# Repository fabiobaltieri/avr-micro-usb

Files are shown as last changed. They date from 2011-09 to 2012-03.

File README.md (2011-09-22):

AVR MICRO USB
==========

This project is a small USB key based on Atmel ATtiny45-like microcontrollers.

License
-------

This program is free software: you can redistribute it and/or modify
it under the terms of the GNU General Public License as published by
the Free Software Foundation, either version 2 of the License, or
(at your option) any later version.

Contents
--------

    COPYING     text version of the GPL
    README      this file
    firmware/   source directory for firmware files
    hardware/   source directory for the hardware design files

Firmware
--------

Building requires an avr-gcc toolchain, in the firmware/ directory, to build
run:

    make main.hex

Flashing the firmware on the device requires avrdude and a compatible hardware
programmer. Default configuration is stored at the beginning of the Makefile.
To program with the default configuration, run:

    make flash

Fuses can be configured running:

    make fuses

Hardware
--------

All hardware files (schematic, layout and libraries) are in CadSoft Eagle
format.

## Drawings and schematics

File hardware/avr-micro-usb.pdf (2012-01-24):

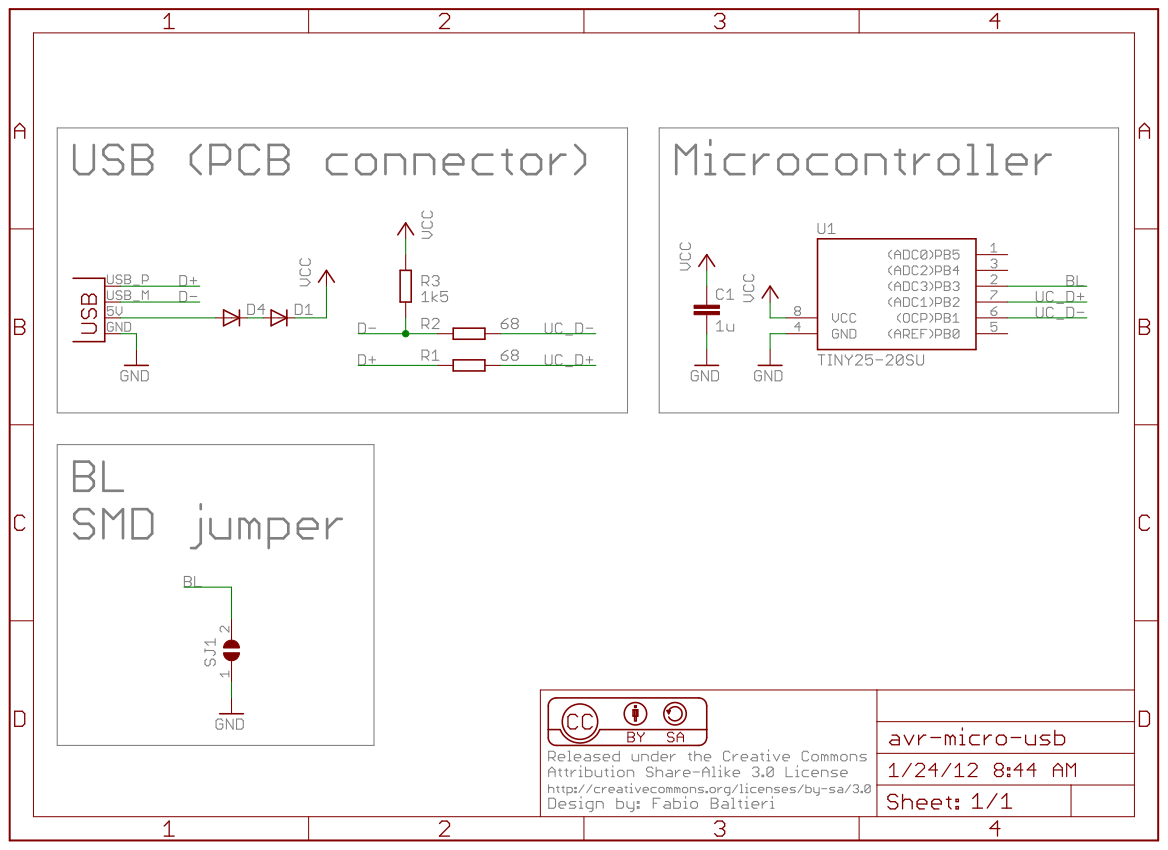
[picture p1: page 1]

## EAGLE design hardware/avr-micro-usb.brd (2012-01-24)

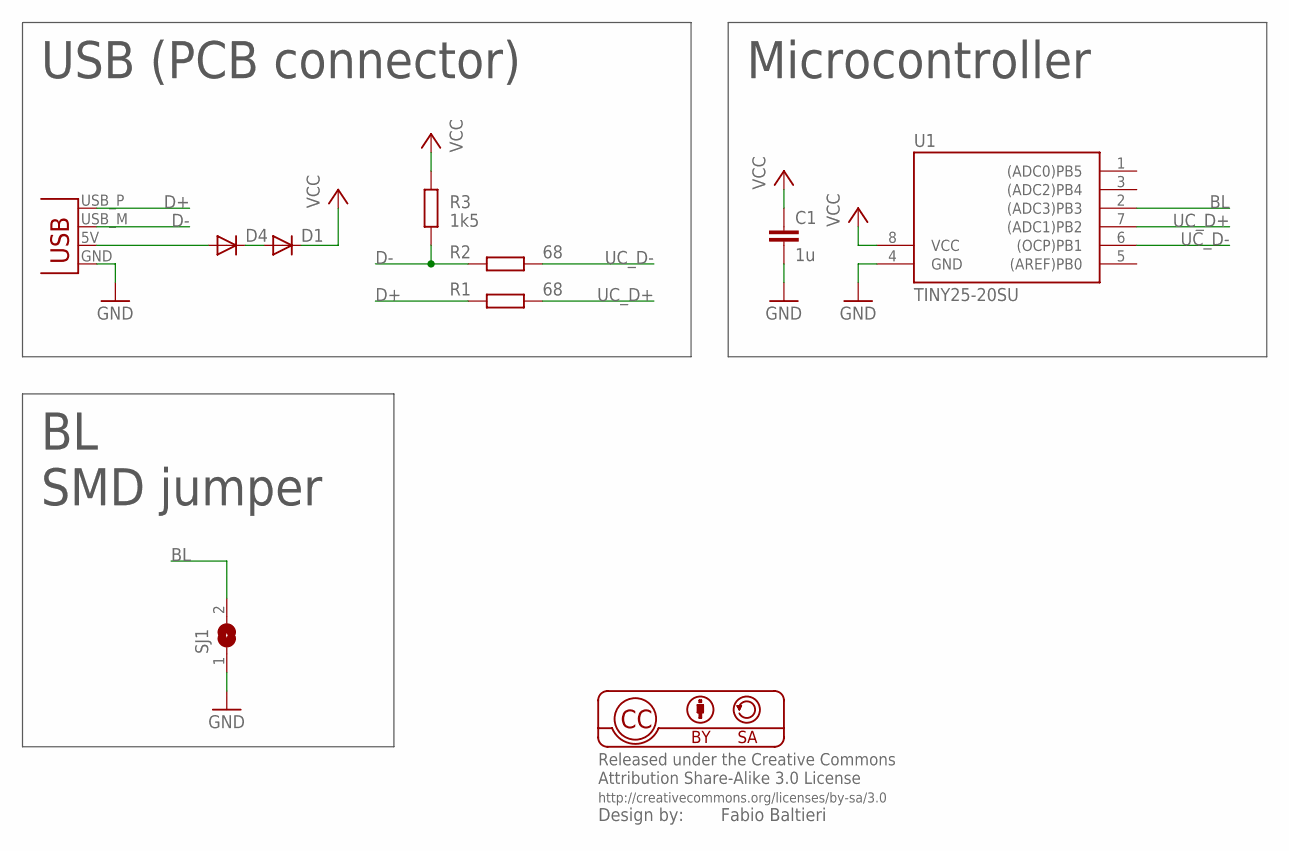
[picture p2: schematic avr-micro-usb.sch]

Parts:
C1: 1u; C0805
D1, D4: DIODE-MINIMELF; MINIMELF
R1, R2: 68; R0603
R3: 1k5; R0603
SJ1: SJ
U1: TINY25-20SU; SOIC8
X1: USBPCB; USB-A-PCB

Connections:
BL: SJ1.2, U1.2 ((ADC3)PB3)
D+: R1.2, X1.USB_P (D+)
D-: R2.2, R3.1, X1.USB_M (D-)
GND: C1.2, SJ1.1, U1.4 (GND), X1.GND
unnamed: D4.A, X1.5V (VBUS)
unnamed: D1.A, D4.C
UC_D+: R1.1, U1.7 ((ADC1)PB2)
UC_D-: R2.1, U1.6 ((OCP)PB1)
VCC: C1.1, D1.C, R3.2, U1.8 (VCC)

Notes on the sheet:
USB (PCB connector)
SMD jumper
Microcontroller

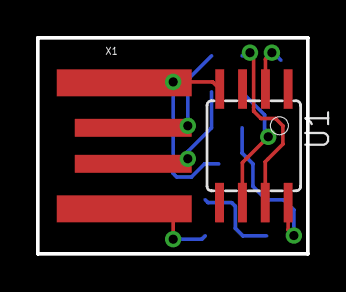
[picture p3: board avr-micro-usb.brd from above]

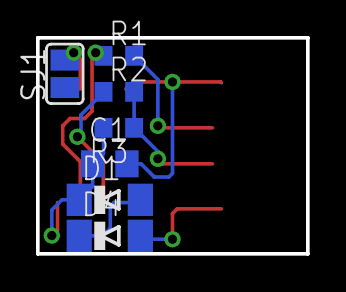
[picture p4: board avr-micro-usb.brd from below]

Board: 2 copper layers, 15.0 x 12.0 mm, 9 parts (7 on the bottom side), 9 nets.

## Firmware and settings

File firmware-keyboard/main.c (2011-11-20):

/*
 * Copyright 2011 Fabio Baltieri (fabio.baltieri@gmail.com)
 *
 * Based on the original V-USB code written by
 *  Christian Starkjohann, Copyright 2006, OBJECTIVE DEVELOPMENT Software GmbH
 *
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
 */

#include <avr/io.h>
#include <avr/interrupt.h>
#include <avr/pgmspace.h>
#include <avr/eeprom.h>
#include <avr/wdt.h>
#include <string.h>

#include "usbdrv.h"
#include "oddebug.h"

/* ----------------------- hardware I/O abstraction ------------------------ */

static void hardwareInit(void)
{
  uchar	i, j;

  PORTB = 0x08;   /* activate all pull-ups */
  DDRB = 0;       /* all pins input */
  j = 0;
  while(--j){     /* USB Reset by device only required on Watchdog Reset */
    i = 0;
    while(--i); /* delay >10ms for USB reset */
  }
  DDRB = 0x08;    /* 0000 0010 bin: remove USB reset condition */
  /* configure timer 0 for a rate of 12M/(1024 * 256) = 45.78 Hz (~22ms) */
  TCCR0A = 5;      /* timer 0 prescaler: 1024 */
}

/* ------------------------------------------------------------------------- */
/* ----------------------------- USB interface ----------------------------- */
/* ------------------------------------------------------------------------- */

static uchar    reportBuffer[8];    /* buffer for HID reports */
static uint8_t  reportIndex;
static uchar    idleRate;           /* in 4 ms units */

PROGMEM char usbHidReportDescriptor[USB_CFG_HID_REPORT_DESCRIPTOR_LENGTH] = { /* USB report descriptor */
  0x05, 0x01,                    // USAGE_PAGE (Generic Desktop)
  0x09, 0x06,                    // USAGE (Keyboard)
  0xa1, 0x01,                    // COLLECTION (Application)

  0x05, 0x07,                    //   USAGE_PAGE (Keyboard)
  0x19, 0xe0,                    //   USAGE_MINIMUM (Keyboard LeftControl)
  0x29, 0xe7,                    //   USAGE_MAXIMUM (Keyboard Right GUI)
  0x15, 0x00,                    //   LOGICAL_MINIMUM (0)
  0x25, 0x01,                    //   LOGICAL_MAXIMUM (1)
  0x75, 0x01,                    //   REPORT_SIZE (1)
  0x95, 0x08,                    //   REPORT_COUNT (8)
  0x81, 0x02,                    //   INPUT (Data,Var,Abs)

  0x95, 0x01,                    //   REPORT_COUNT (1)
  0x75, 0x08,                    //   REPORT_SIZE (8)
  0x81, 0x03,                    //   INPUT (Cnst,Var,Abs)

  0x95, 0x06,                    //   REPORT_COUNT (6)
  0x75, 0x08,                    //   REPORT_SIZE (8)
  0x25, 0xff,                    //   LOGICAL_MAXIMUM (101)
  0x19, 0x00,                    //   USAGE_MINIMUM (Reserved (no event indicated))
  0x29, 0xff,                    //   USAGE_MAXIMUM (Keyboard Application)
  0x81, 0x00,                    //   INPUT (Data,Ary,Abs)

  0xc0                           // END_COLLECTION
};
/* We use a simplifed keyboard report descriptor which does not support the
 * boot protocol. We don't allow setting status LEDs and we only allow one
 * simultaneous key press (except modifiers). We can therefore use short
 * 2 byte input reports.
 * The report descriptor has been created with usb.org's "HID Descriptor Tool"
 * which can be downloaded from http://www.usb.org/developers/hidpage/.
 * Redundant entries (such as LOGICAL_MINIMUM and USAGE_PAGE) have been omitted
 * for the second INPUT item.
 */

/* Keyboard usage values, see usb.org's HID-usage-tables document, chapter
 * 10 Keyboard/Keypad Page for more codes.
 */
#define MOD_CONTROL_LEFT    (1<<0)
#define MOD_SHIFT_LEFT      (1<<1)
#define MOD_ALT_LEFT        (1<<2)
#define MOD_GUI_LEFT        (1<<3)
#define MOD_CONTROL_RIGHT   (1<<4)
#define MOD_SHIFT_RIGHT     (1<<5)
#define MOD_ALT_RIGHT       (1<<6)
#define MOD_GUI_RIGHT       (1<<7)

#define KEY_A       4
#define KEY_B       5
#define KEY_C       6
#define KEY_D       7
#define KEY_E       8
#define KEY_F       9
#define KEY_G       10
#define KEY_H       11
#define KEY_I       12
#define KEY_J       13
#define KEY_K       14
#define KEY_L       15
#define KEY_M       16
#define KEY_N       17
#define KEY_O       18
#define KEY_P       19
#define KEY_Q       20
#define KEY_R       21
#define KEY_S       22
#define KEY_T       23
#define KEY_U       24
#define KEY_V       25
#define KEY_W       26
#define KEY_X       27
#define KEY_Y       28
#define KEY_Z       29
#define KEY_1       30
#define KEY_2       31
#define KEY_3       32
#define KEY_4       33
#define KEY_5       34
#define KEY_6       35
#define KEY_7       36
#define KEY_8       37
#define KEY_9       38
#define KEY_0       39

#define KEY_RETURN  40

#define KEY_F1      58
#define KEY_F2      59
#define KEY_F3      60
#define KEY_F4      61
#define KEY_F5      62
#define KEY_F6      63
#define KEY_F7      64
#define KEY_F8      65
#define KEY_F9      66
#define KEY_F10     67
#define KEY_F11     68
#define KEY_F12     69

#define KEY_RIGHT   79
#define KEY_LEFT    80
#define KEY_DOWN    81
#define KEY_UP      82

#define KEY_MENU    227

static void report(uint8_t modifier, uint8_t key)
{
  uint8_t i;

  if (modifier)
    reportBuffer[0] |= modifier;

  if (key) {
    for (i = 2; i < sizeof(reportBuffer); i++)
      if (reportBuffer[i] == key)
	return;

    if (reportIndex == sizeof(reportBuffer)) {
      memset(&reportBuffer[2], 1, sizeof(reportBuffer) - 2); /* phantom state */
    } else {
      reportBuffer[reportIndex++] = key;
    }
  }
}

static uint16_t buildReport(void)
{
  uint8_t tmp;
  uint16_t ret;

  memset(reportBuffer, 0, sizeof(reportBuffer));
  reportIndex = 2;

  tmp = PINB;
  if ((tmp & _BV(3)) == 0) report(0, KEY_MENU);
  ret = tmp & 0x08;

  return ret;
}

uchar	usbFunctionSetup(uchar data[8])
{
  usbRequest_t    *rq = (void *)data;

  usbMsgPtr = reportBuffer;
  if((rq->bmRequestType & USBRQ_TYPE_MASK) == USBRQ_TYPE_CLASS){    /* class request type */
    if(rq->bRequest == USBRQ_HID_GET_REPORT){  /* wValue: ReportType (highbyte), ReportID (lowbyte) */
      /* we only have one report type, so don't look at wValue */
      buildReport();
      return sizeof(reportBuffer);
    }else if(rq->bRequest == USBRQ_HID_GET_IDLE){
      usbMsgPtr = &idleRate;
      return 1;
    }else if(rq->bRequest == USBRQ_HID_SET_IDLE){
      idleRate = rq->wValue.bytes[1];
    }
  }else{
    /* no vendor specific requests implemented */
  }
  return 0;
}

/* ------------------------------------------------------------------------- */
/* ------------------------ Oscillator Calibration ------------------------- */
/* ------------------------------------------------------------------------- */

/* Calibrate the RC oscillator to 8.25 MHz. The core clock of 16.5 MHz is
 * derived from the 66 MHz peripheral clock by dividing. Our timing reference
 * is the Start Of Frame signal (a single SE0 bit) available immediately after
 * a USB RESET. We first do a binary search for the OSCCAL value and then
 * optimize this value with a neighboorhod search.
 * This algorithm may also be used to calibrate the RC oscillator directly to
 * 12 MHz (no PLL involved, can therefore be used on almost ALL AVRs), but this
 * is wide outside the spec for the OSCCAL value and the required precision for
 * the 12 MHz clock! Use the RC oscillator calibrated to 12 MHz for
 * experimental purposes only!
 */
static void calibrateOscillator(void)
{
uchar       step = 128;
uchar       trialValue = 0, optimumValue;
int         x, optimumDev, targetValue = (unsigned)(1499 * (double)F_CPU / 10.5e6 + 0.5);

    /* do a binary search: */
    do{
        OSCCAL = trialValue + step;
        x = usbMeasureFrameLength();    /* proportional to current real frequency */
        if(x < targetValue)             /* frequency still too low */
            trialValue += step;
        step >>= 1;
    }while(step > 0);
    /* We have a precision of +/- 1 for optimum OSCCAL here */
    /* now do a neighborhood search for optimum value */
    optimumValue = trialValue;
    optimumDev = x; /* this is certainly far away from optimum */
    for(OSCCAL = trialValue - 1; OSCCAL <= trialValue + 1; OSCCAL++){
        x = usbMeasureFrameLength() - targetValue;
        if(x < 0)
            x = -x;
        if(x < optimumDev){
            optimumDev = x;
            optimumValue = OSCCAL;
        }
    }
    OSCCAL = optimumValue;
}
/*
Note: This calibration algorithm may try OSCCAL values of up to 192 even if
the optimum value is far below 192. It may therefore exceed the allowed clock
frequency of the CPU in low voltage designs!
You may replace this search algorithm with any other algorithm you like if
you have additional constraints such as a maximum CPU clock.
For version 5.x RC oscillators (those with a split range of 2x128 steps, e.g.
ATTiny25, ATTiny45, ATTiny85), it may be useful to search for the optimum in
both regions.
*/

void    hadUsbReset(void)
{
    calibrateOscillator();
    eeprom_write_byte(0, OSCCAL);   /* store the calibrated value in EEPROM */
}

/* ------------------------------------------------------------------------- */

int	main(void)
{
  uchar   keyDidChange = 1;
  uchar   idleCounter = 0;
  uint16_t key, lastKey = 0;
  uchar   calibrationValue;

  calibrationValue = eeprom_read_byte(0); /* calibration value from last time */
  if(calibrationValue != 0xff){
    OSCCAL = calibrationValue;
  }

  CLKPR = _BV(CLKPCE);
  CLKPR = 0x00;

  wdt_enable(WDTO_2S);

  hardwareInit();
  odDebugInit();
  usbInit();

  sei();

  DBG1(0x00, 0, 0);
  for(;;){	/* main event loop */

    wdt_reset();
    usbPoll();

    key = buildReport();
    if(lastKey != key){
      lastKey = key;
      keyDidChange = 1;
    }

    if(TIFR & (1<<TOV0)){   /* 22 ms timer */
      TIFR = 1<<TOV0;
      if(idleRate != 0){
	if(idleCounter > 4){
	  idleCounter -= 5;   /* 22 ms in units of 4 ms */
	}else{
	  idleCounter = idleRate;
	  keyDidChange = 1;
	}
      }
    }

    if(keyDidChange && usbInterruptIsReady()){
      keyDidChange = 0;
      usbSetInterrupt(reportBuffer, sizeof(reportBuffer));
    }

  }
  return 0;
}

/* ------------------------------------------------------------------------- */

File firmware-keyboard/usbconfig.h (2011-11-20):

/*
 * Copyright 2011 Fabio Baltieri (fabio.baltieri@gmail.com)
 *
 * Based on the original V-USB code written by
 *  Christian Starkjohann, Copyright 2005, OBJECTIVE DEVELOPMENT Software GmbH
 *
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
 */

#ifndef __usbconfig_h_included__
#define __usbconfig_h_included__

/*
General Description:
This file is an example configuration (with inline documentation) for the USB
driver. It configures V-USB for USB D+ connected to Port D bit 2 (which is
also hardware interrupt 0 on many devices) and USB D- to Port D bit 4. You may
wire the lines to any other port, as long as D+ is also wired to INT0 (or any
other hardware interrupt, as long as it is the highest level interrupt, see
section at the end of this file).
*/

/* ---------------------------- Hardware Config ---------------------------- */

#define USB_CFG_IOPORTNAME      B
/* This is the port where the USB bus is connected. When you configure it to
 * "B", the registers PORTB, PINB and DDRB will be used.
 */
#define USB_CFG_DMINUS_BIT      1
/* This is the bit number in USB_CFG_IOPORT where the USB D- line is connected.
 * This may be any bit in the port.
 */
#define USB_CFG_DPLUS_BIT       2
/* This is the bit number in USB_CFG_IOPORT where the USB D+ line is connected.
 * This may be any bit in the port. Please note that D+ must also be connected
 * to interrupt pin INT0! [You can also use other interrupts, see section
 * "Optional MCU Description" below, or you can connect D- to the interrupt, as
 * it is required if you use the USB_COUNT_SOF feature. If you use D- for the
 * interrupt, the USB interrupt will also be triggered at Start-Of-Frame
 * markers every millisecond.]
 */
#define USB_CFG_CLOCK_KHZ       (F_CPU/1000)
/* Clock rate of the AVR in kHz. Legal values are 12000, 12800, 15000, 16000,
 * 16500, 18000 and 20000. The 12.8 MHz and 16.5 MHz versions of the code
 * require no crystal, they tolerate +/- 1% deviation from the nominal
 * frequency. All other rates require a precision of 2000 ppm and thus a
 * crystal!
 * Since F_CPU should be defined to your actual clock rate anyway, you should
 * not need to modify this setting.
 */
#define USB_CFG_CHECK_CRC       0
/* Define this to 1 if you want that the driver checks integrity of incoming
 * data packets (CRC checks). CRC checks cost quite a bit of code size and are
 * currently only available for 18 MHz crystal clock. You must choose
 * USB_CFG_CLOCK_KHZ = 18000 if you enable this option.
 */

/* ----------------------- Optional Hardware Config ------------------------ */

/* #define USB_CFG_PULLUP_IOPORTNAME   D */
/* If you connect the 1.5k pullup resistor from D- to a port pin instead of
 * V+, you can connect and disconnect the device from firmware by calling
 * the macros usbDeviceConnect() and usbDeviceDisconnect() (see usbdrv.h).
 * This constant defines the port on which the pullup resistor is connected.
 */
/* #define USB_CFG_PULLUP_BIT          4 */
/* This constant defines the bit number in USB_CFG_PULLUP_IOPORT (defined
 * above) where the 1.5k pullup resistor is connected. See description
 * above for details.
 */

/* --------------------------- Functional Range ---------------------------- */
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

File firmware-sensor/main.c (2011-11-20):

/*
 * Copyright 2011 Fabio Baltieri (fabio.baltieri@gmail.com)
 *
 * Based on the original V-USB code written by
 *  Christian Starkjohann, Copyright 2008, OBJECTIVE DEVELOPMENT Software GmbH
 *
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
 */

#include <avr/io.h>
#include <avr/wdt.h>
#include <avr/interrupt.h>  /* for sei() */
#include <util/delay.h>     /* for _delay_ms() */

#include <avr/pgmspace.h>   /* required by usbdrv.h */
#include <avr/eeprom.h>   /* required by usbdrv.h */
#include "usbdrv.h"
#include "oddebug.h"        /* This is also an example for using debug macros */
#include "requests.h"       /* The custom request numbers we use */

#include "adc.h"

/* ------------------------------------------------------------------------- */
/* ----------------------------- USB interface ----------------------------- */
/* ------------------------------------------------------------------------- */

usbMsgLen_t usbFunctionSetup(uchar data[8])
{
  usbRequest_t    *rq = (void *)data;
  static unsigned char dataBuffer[4];
  static int16_t  val;  /* buffer must stay valid when usbFunctionSetup returns */

  if(rq->bRequest == CUSTOM_RQ_ECHO){ /* echo -- used for reliability tests */
    dataBuffer[0] = rq->wValue.bytes[0];
    dataBuffer[1] = rq->wValue.bytes[1];
    dataBuffer[2] = rq->wIndex.bytes[0];
    dataBuffer[3] = rq->wIndex.bytes[1];
    usbMsgPtr = dataBuffer;         /* tell the driver which data to return */
    return 4;
  }else if(rq->bRequest == CUSTOM_RQ_ADC0){
    val  = adc_get(ADMUX_REF_VCC | ADMUX_MUX_ADC3);
    val += adc_get(ADMUX_REF_VCC | ADMUX_MUX_ADC3);
    val += adc_get(ADMUX_REF_VCC | ADMUX_MUX_ADC3);
    val += adc_get(ADMUX_REF_VCC | ADMUX_MUX_ADC3);
    val /= 4;
    usbMsgPtr = (unsigned char *)&val;         /* tell the driver which data to return */
    return 2;
  }else if(rq->bRequest == CUSTOM_RQ_ADC1){
    val  = adc_get(ADMUX_REF_1V1 | ADMUX_MUX_TEMP);
    val += adc_get(ADMUX_REF_1V1 | ADMUX_MUX_TEMP);
    val += adc_get(ADMUX_REF_1V1 | ADMUX_MUX_TEMP);
    val += adc_get(ADMUX_REF_1V1 | ADMUX_MUX_TEMP);
    val /= 4;
    usbMsgPtr = (unsigned char *)&val;         /* tell the driver which data to return */
    return 2;
  }
  return 0;   /* default for not implemented requests: return no data back to host */
}

static void calibrateOscillator(void)
{
  uchar       step = 128;
  uchar       trialValue = 0, optimumValue;
  int         x, optimumDev, targetValue = (unsigned)(1499 * (double)F_CPU / 10.5e6 + 0.5);

  /* do a binary search: */
  do{
    OSCCAL = trialValue + step;
    x = usbMeasureFrameLength();    /* proportional to current real frequency */
    if(x < targetValue)             /* frequency still too low */
      trialValue += step;
    step >>= 1;
  }while(step > 0);
  /* We have a precision of +/- 1 for optimum OSCCAL here */
  /* now do a neighborhood search for optimum value */
  optimumValue = trialValue;
  optimumDev = x; /* this is certainly far away from optimum */
  for(OSCCAL = trialValue - 1; OSCCAL <= trialValue + 1; OSCCAL++){
    x = usbMeasureFrameLength() - targetValue;
    if(x < 0)
      x = -x;
    if(x < optimumDev){
      optimumDev = x;
      optimumValue = OSCCAL;
    }
  }
  OSCCAL = optimumValue;
}

void    hadUsbReset(void)
{
  calibrateOscillator();
  eeprom_write_byte(0, OSCCAL);   /* store the calibrated value in EEPROM */
}


/* ------------------------------------------------------------------------- */

int __attribute__((noreturn)) main(void)
{
  uchar   i;
  uchar   calibrationValue;

  calibrationValue = eeprom_read_byte(0); /* calibration value from last time */
  if(calibrationValue != 0xff){
    OSCCAL = calibrationValue;
  }

  wdt_enable(WDTO_1S);
  /* Even if you don't use the watchdog, turn it off here. On newer devices,
   * the status of the watchdog (on/off, period) is PRESERVED OVER RESET!
   */
  /* RESET status: all port bits are inputs without pull-up.
   * That's the way we need D+ and D-. Therefore we don't need any
   * additional hardware initialization.
   */
  odDebugInit();
  DBG1(0x00, 0, 0);       /* debug output: main starts */
  usbInit();
  usbDeviceDisconnect();  /* enforce re-enumeration, do this while interrupts are disabled! */
  i = 0;
  while(--i){             /* fake USB disconnect for > 250 ms */
    wdt_reset();
    _delay_ms(1);
  }
  usbDeviceConnect();
  sei();
  DBG1(0x01, 0, 0);       /* debug output: main loop starts */
  for(;;){                /* main event loop */
    DBG1(0x02, 0, 0);   /* debug output: main loop iterates */
    wdt_reset();
    usbPoll();
  }
}

/* ------------------------------------------------------------------------- */

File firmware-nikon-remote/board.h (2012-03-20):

/* LEDs */

#define LED_PORT      PORTB
#define LED_DDR       DDRB
#define LED_IR        PB3
#define LED_R         PB0

#define led_ir_on() do {			\
		LED_PORT &= ~_BV(LED_IR);	\
		LED_PORT |=  _BV(LED_R);	\
	} while (0)
#define led_r_on() do {					\
		LED_PORT |=  _BV(LED_IR);		\
		LED_PORT &= ~_BV(LED_R);		\
	} while (0)

#define led_off() do {						\
		LED_PORT &= ~(_BV(LED_IR) | _BV(LED_R));	\
	} while (0)

#define led_init() do {					\
		LED_DDR |= _BV(LED_IR) | _BV(LED_R);	\
	} while (0);

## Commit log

2011-09-22 hardware: add hardware directory
    [avr-micro-usb.brd, avr-micro-usb.sch]
2011-09-22 hardware: add schematics in pdf version
2011-09-25 firmware-sensor: add firmware for key in sensor mode
2011-10-19 main: remove wrong port configurations for attiny25
    [main.c]
2011-11-20 hardware: add CC BY-SA license
    [avr-micro-usb.brd, avr-micro-usb.sch]
2012-01-24 hardware: convert files to v6, cosmetic changes
    [avr-micro-usb.brd, avr-micro-usb.sch]
2012-04-01 nikon-trigger: change device name to IR-Trigger
2012-05-05 kernel-led: add avr-usb-led driver

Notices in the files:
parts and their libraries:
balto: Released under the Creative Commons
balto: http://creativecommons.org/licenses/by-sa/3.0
